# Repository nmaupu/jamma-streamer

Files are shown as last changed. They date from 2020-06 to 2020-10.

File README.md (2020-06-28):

# jamma-streamer

Jamma PCB video recorder and more (hardware)

# Eagle library and parts used

* `nma-eagle` library: https://github.com/nmaupu/electronics/blob/master/eagle-libs/nma-eagle.lbr
* SparkFun libraries (https://github.com/sparkfun/SparkFun-Eagle-Libraries):
  - SparkFun-Connectors
  - SparkFun-IC-Comms
  - SparkFun-PowerSymbols
  - SparkFun-Retired
* Default eagle libraries:
  - linear
  - pinhead
  - jumper

# BOM (Bill Of Materials) generation

To generate the BOM, use process described in [electronics](https://github.com/nmaupu/electronics) repository !

# RTC

## Interrupts for milliseconds counting

* We will be using the chip `DS3231`. Pin `INT/SWQ` is the one.
* Datasheet https://datasheets.maximintegrated.com/en/ds/DS3231.pdf page 13 indicates how to configure the register to enable a 1KHz signal on this pin.
* The configuration of the register should be: `0b10001000`.
* Configuration is done using I2C protocol.
* `PC3` for `pin change interrupt` on the ATmega side.

Example on how to use `PCINT` is available here: https://gist.github.com/Wollw/2598827

Example on how to configure chip registers via I2C: https://github.com/FabioCuomo/FabioCuomo-DS3231/blob/master/RTClibExtended.cpp

# Buttons detection

Buttons detection are done using shift registers (8 bits parallel in / serial out such as the 75HC165).
The code used is strongly inspired from the following tutorial:
https://playground.arduino.cc/Code/ShiftRegSN74HC165N

# uSDCARD writing

Source:
https://learn.adafruit.com/adafruit-micro-sd-breakout-board-card-tutorial?view=all

Beware: Arduino pins number and macros you can use in your code are sometimes not equivalent to what you expect when using third party libraries like the one used for SD card... One example is the pin `PB2` (Arduino's pin number 10) used for `CS`. If you use the library's macro `PB2`, it sets the pin to number `2` instead of `10`... This leads to long painful debugging session...

Here is an image with all pin numbers as a reference:
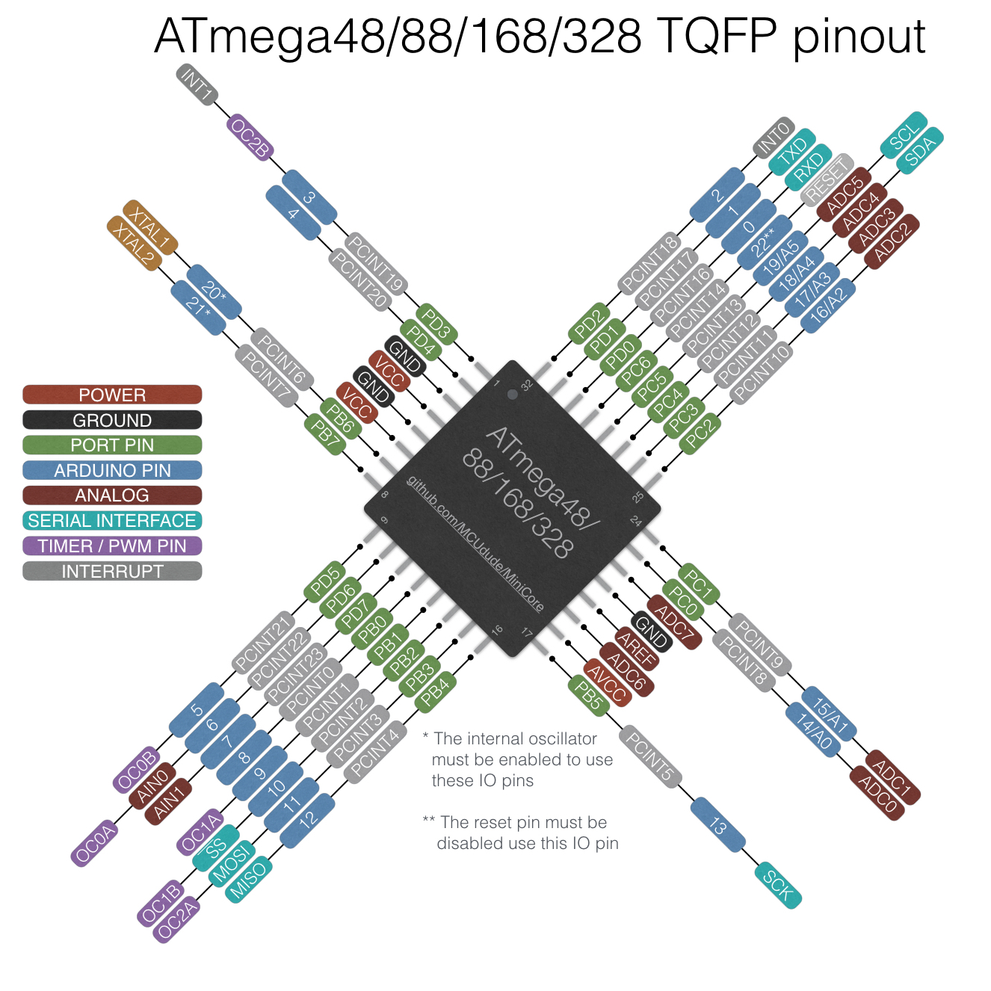
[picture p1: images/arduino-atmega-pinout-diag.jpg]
Arduino ATmega pinout diagram


# How to program the ATMEGA328PB

## Fuses

Fuses can be calculated using: https://www.engbedded.com/fusecalc/

More info here: http://www.martyncurrey.com/arduino-atmega-328p-fuse-settings/

## Using arduino bootloader (for debugging and fast upload via IDE)

We are going to use [Minicore](https://github.com/MCUdude/MiniCore) as it supports ATmega328PB used on this project.

---

Use the following procedure:

- First install minicore boards following the [procedure](https://github.com/MCUdude/MiniCore#boards-manager-installation).

Use *arduino as ISP* method to upload the bootloader:
  - configure your IDE to use the source Arduino which will act as a programmer (ISP programmer)
  - upload Arduino ISP sketch to the arduino board to make it act as an *ISP programmer* (available as example sketch from the Arduino IDE)
  - plug all *Jamma Streamer's ICSP* to *Arduino ICSP* except *RST* both sides
  - *RST Jamma Streamer* (from ICSP) to *pin 10* of the Arduino (this will act as the reset pin)
  - plug a 10uF capacitor between Arduino RESET (capacitor +) and GND (capacitor -)

Now configure the board as per the following:
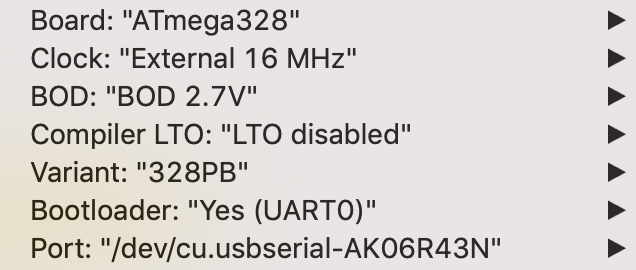
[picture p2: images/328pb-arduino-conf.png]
Arduino configuration for Minicore / ATmega328PB


Your arduino is ready for ISP. Now you can configure to burn the bootloader:
  - `Tools > Port`: select the arduino device
  - `Tools > Burn Bootloader`

This should work as expected. From now on, you will be able to upload sketches via *NMA Jamma Streamer* USB port directly!

Fuses consideration:
  - *Minicore* is forked from *Optiboot* (official Arduino UNO bootloader) and is `512 bytes` long.
  - We are using an external crystal oscillator (and not the internal one).
  - `EEPROM` save is enabled (this avoid erasing it at each upload reducing its lifetime).
  - `BOOTSZ1` and `BOOTSZ2` are both disabled because 512 bytes can fit into the minimal 256 words (1 word = 2 bytes).
  - `BOOTRST` is set to indicate we are using a bootloader.
  - `BODLEVEL1` (2.7V) is enabled because why not.

This give the following fuses:
  - low fuse: `0xff`
  - high fuse: `0xd6`
  - extended fuse: `0xf5` (Normally, it would be `0xfd` but after burning, there is a warning so `f5` is a good value)

## Without using arduino bootloader for runtime

We are using Jamma Streamer board ICSP header for this.
No need for a Arduino bootloader, we will be uploading sketch directly via ICSP header !

As I am using Atmega328PB (instead of P), Arduino IDE is not recognizing at first, we need to install this first to have the board available in Arduino’s IDE later on:
https://github.com/nmaupu/ATmega328PB-Testing

---

Plug cables as follow (using Arduino Duemilanove or Mega):

- All ICSP to Arduino ICSP except RST both sides
- RST Jamma Streamer (from icsp) to pin 10 of the arduino
- Plug Arduino via USB to computer and upload ArduinoISP sketch onto it.
- plug a 10uF capacitor between Arduino RESET (capacitor +) and GND (capacitor -)
- select tools > boards > atmega328PB Crystal Clock
- `sketch > Upload using programmer`

This will program the NMA Jamma Streamer ATmega328PB !

## Burn / read fuses (use the crystal oscillator instead of internal one)

Use an external Arduino board to act as an ISP programmer like before:

- All ICSP to Arduino ICSP except RST both sides
- RST Jamma Streamer (from icsp) to pin 10 of the arduino
- Plug Arduino via USB to computer and upload ArduinoISP sketch onto it.
- plug a 10uF capacitor between Arduino RESET (capacitor +) and GND (capacitor -)

To read the fuses, simply execute:
```
avrdude -C /Users/nicolas_maupu/Library/Arduino15/packages/MiniCore/hardware/avr/2.0.5/avrdude.conf \
  -p atmega328pb -c stk500v1 -P /dev/cu.usbmodem141101 -b19200 \
  -U hfuse:r:-:h -U efuse:r:-:h -U lfuse:r:-:h
```

To burn fuses:
```
avrdude -C /Users/nicolas_maupu/Library/Arduino15/packages/MiniCore/hardware/avr/2.0.5/avrdude.conf \
  -v -p atmega328pb -c stk500v1 -P /dev/cu.usbmodem141101 -b19200 \
  -e -Ulock:w:0x3f:m -Uefuse:w:0xF5:m -Uhfuse:w:0xd6:m -Ulfuse:w:0xff:m 
```

To burn the Minicore bootloader:
```
avrdude -C /Users/nicolas_maupu/Library/Arduino15/packages/MiniCore/hardware/avr/2.0.5/avrdude.conf \
  -v -p atmega328pb -c stk500v1 -P /dev/cu.usbmodem141101 -b19200 \
  -Uflash:w:$HOME/Library/Arduino15/packages/MiniCore/hardware/avr/2.0.5/bootloaders/optiboot_flash/bootloaders/atmega328pb/16000000L/optiboot_flash_atmega328pb_UART0_115200_16000000L_B5.hex:i \
  -Ulock:w:0x0f:m 
```

# Thanks

- https://github.com/Shinichi-Ohki/JAMMA_connector_for_eagle
- https://github.com/watterott/wattuino

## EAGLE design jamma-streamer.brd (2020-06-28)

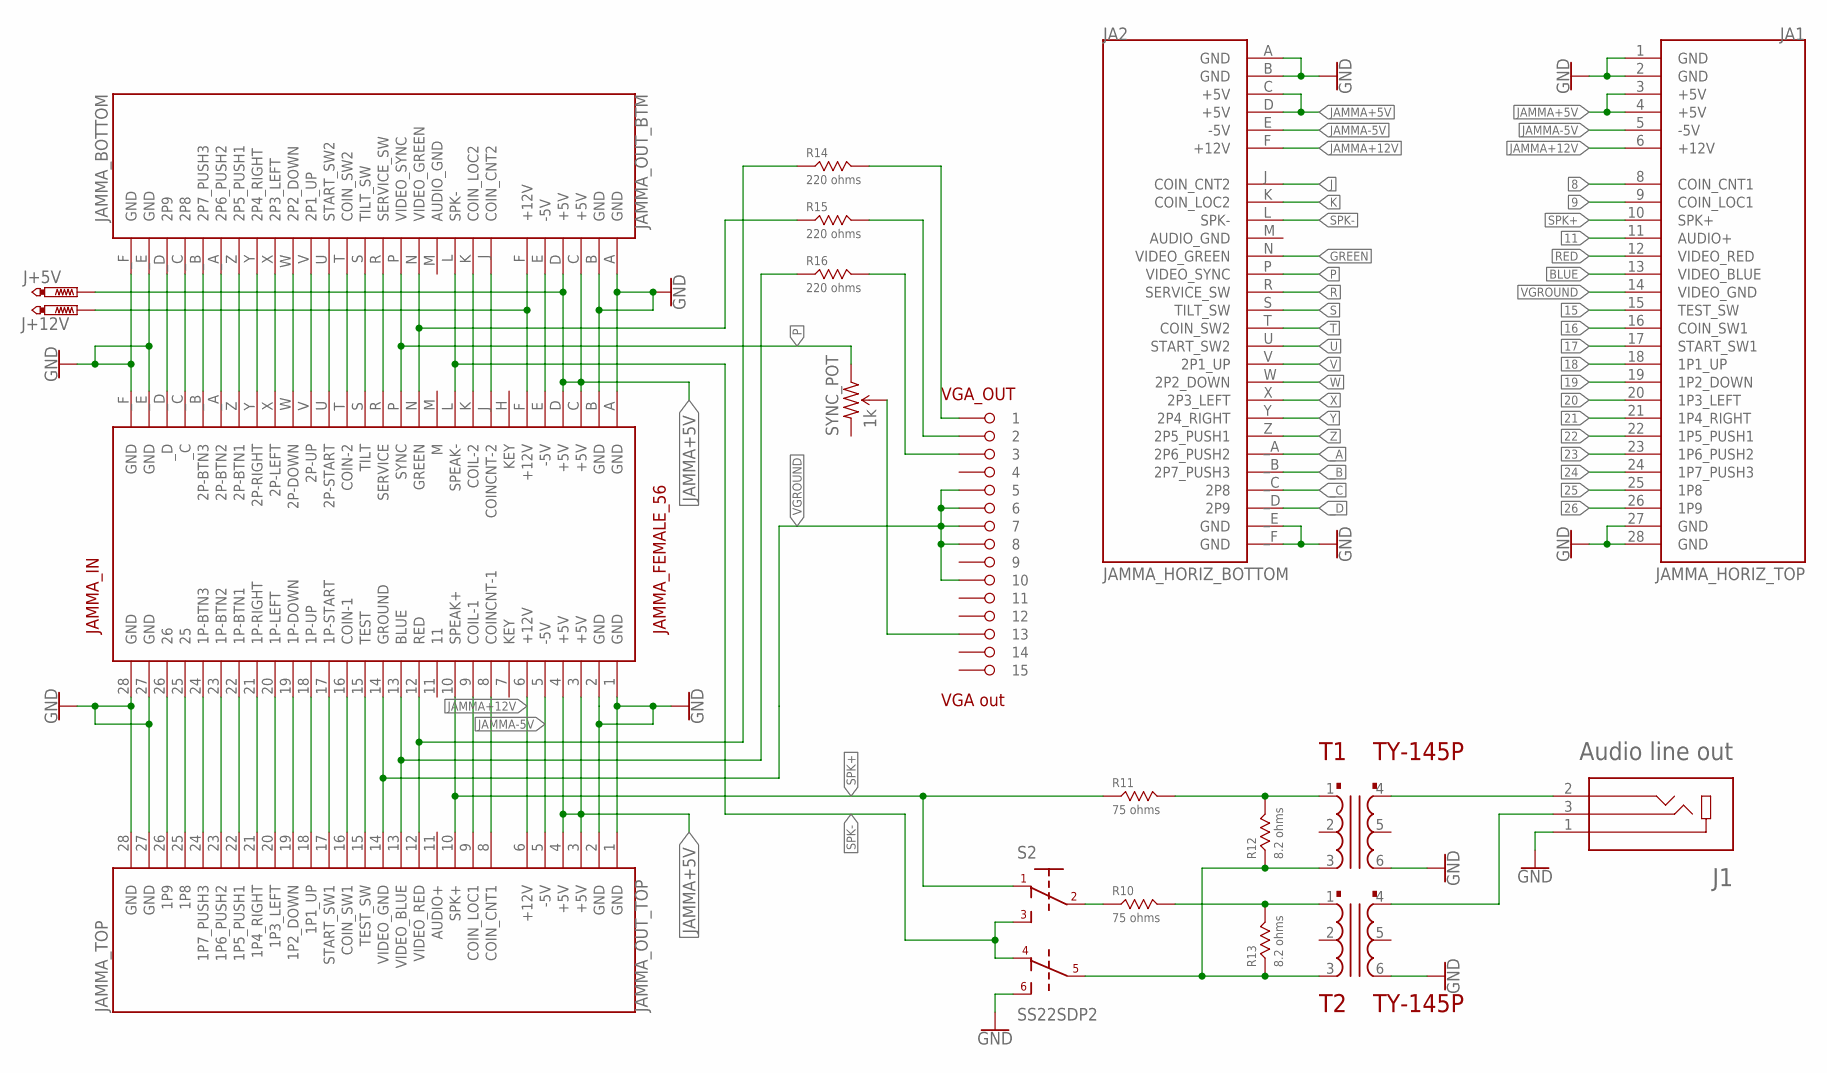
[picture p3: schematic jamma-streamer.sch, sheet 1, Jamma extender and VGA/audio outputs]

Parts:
J1: Audio line out; CUI_SJ1-3523N
J+5V, J+12V: PTR1TP15SQ; TP15SQ
JA1: JAMMA_HORIZ_TOP
JA2: JAMMA_HORIZ_BOTTOM
JAMMA_IN: JAMMA_FEMALE_56
JAMMA_OUT_BTM: JAMMA_BOTTOM
JAMMA_OUT_TOP: JAMMA_TOP
R10, R11: 75 ohms; TE_3550_SERIES; MOUSER_REF 279-355075RFT
R12, R13: 8.2 ohms; TE_3550_SERIES; MOUSER_REF 279-35508R2JT
R14, R15, R16: 220 ohms; RESC3225X70N
S2: SS22SDP2; SS22SDP2(DPDT)
SYNC_POT: 1k; TRIM_POT_PTH
T1, T2: TY-145P; TRIAD-TY-145P
VGA_OUT: VGA out; HARTING-DSUB-15-FEMALE

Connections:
8: JA1.8 (COIN_CNT1), JAMMA_IN.8 (COINCNT-1), JAMMA_OUT_TOP.8 (COIN_CNT1)
9: JA1.9 (COIN_LOC1), JAMMA_IN.9 (COIL-1), JAMMA_OUT_TOP.9 (COIN_LOC1)
11: JA1.11 (AUDIO+)
15: JA1.15 (TEST_SW), JAMMA_IN.15 (TEST), JAMMA_OUT_TOP.15 (TEST_SW); also elsewhere on the board
16: JA1.16 (COIN_SW1), JAMMA_IN.16 (COIN-1), JAMMA_OUT_TOP.16 (COIN_SW1); also elsewhere on the board
17: JA1.17 (START_SW1), JAMMA_IN.17 (1P-START), JAMMA_OUT_TOP.17 (START_SW1); also elsewhere on the board
18: JA1.18 (1P1_UP), JAMMA_IN.18 (1P-UP), JAMMA_OUT_TOP.18 (1P1_UP); also elsewhere on the board
19: JA1.19 (1P2_DOWN), JAMMA_IN.19 (1P-DOWN), JAMMA_OUT_TOP.19 (1P2_DOWN); also elsewhere on the board
20: JA1.20 (1P3_LEFT), JAMMA_IN.20 (1P-LEFT), JAMMA_OUT_TOP.20 (1P3_LEFT); also elsewhere on the board
21: JA1.21 (1P4_RIGHT), JAMMA_IN.21 (1P-RIGHT), JAMMA_OUT_TOP.21 (1P4_RIGHT); also elsewhere on the board
22: JA1.22 (1P5_PUSH1), JAMMA_IN.22 (1P-BTN1), JAMMA_OUT_TOP.22 (1P5_PUSH1); also elsewhere on the board
23: JA1.23 (1P6_PUSH2), JAMMA_IN.23 (1P-BTN2), JAMMA_OUT_TOP.23 (1P6_PUSH2); also elsewhere on the board
24: JA1.24 (1P7_PUSH3), JAMMA_IN.24 (1P-BTN3), JAMMA_OUT_TOP.24 (1P7_PUSH3); also elsewhere on the board
25: JA1.25 (1P8), JAMMA_IN.25, JAMMA_OUT_TOP.25 (1P8); also elsewhere on the board
26: JA1.26 (1P9), JAMMA_IN.26, JAMMA_OUT_TOP.26 (1P9); also elsewhere on the board
BLUE: JA1.13 (VIDEO_BLUE), JAMMA_IN.13 (BLUE), JAMMA_OUT_TOP.13 (VIDEO_BLUE), R16.1
GND: J1.1, JA1.1 (GND), JA1.2 (GND), JA1.27 (GND), JA1.28 (GND), JA2.A (GND), JA2.B (GND), JA2._E (GND), JA2._F (GND), JAMMA_IN.1 (GND), JAMMA_IN.2 (GND), JAMMA_IN.27 (GND), JAMMA_IN.28 (GND), JAMMA_IN.A (GND), JAMMA_IN.B (GND), JAMMA_IN._E (GND), JAMMA_IN._F (GND), JAMMA_OUT_BTM.A (GND), JAMMA_OUT_BTM.B (GND), JAMMA_OUT_BTM._E (GND), JAMMA_OUT_BTM._F (GND), JAMMA_OUT_TOP.1 (GND), JAMMA_OUT_TOP.2 (GND), JAMMA_OUT_TOP.27 (GND), JAMMA_OUT_TOP.28 (GND), S2.6, T1.6, T2.6; also elsewhere on the board
GREEN: JA2.N (VIDEO_GREEN), JAMMA_IN.N (GREEN), JAMMA_OUT_BTM.N (VIDEO_GREEN), R15.1
J: JA2.J (COIN_CNT2), JAMMA_IN.J (COINCNT-2), JAMMA_OUT_BTM.J (COIN_CNT2)
JAMMA+5V: J+5V.TP, JA1.3 (+5V), JA1.4 (+5V), JA2.C (+5V), JA2.D (+5V), JAMMA_IN.3 (+5V), JAMMA_IN.4 (+5V), JAMMA_IN.C (+5V), JAMMA_IN.D (+5V), JAMMA_OUT_BTM.C (+5V), JAMMA_OUT_BTM.D (+5V), JAMMA_OUT_TOP.3 (+5V), JAMMA_OUT_TOP.4 (+5V)
JAMMA+12V: J+12V.TP, JA1.6 (+12V), JA2.F (+12V), JAMMA_IN.6 (+12V), JAMMA_IN.F (+12V), JAMMA_OUT_BTM.F (+12V), JAMMA_OUT_TOP.6 (+12V); also elsewhere on the board
JAMMA-5V: JA1.5 (-5V), JA2.E (-5V), JAMMA_IN.5 (-5V), JAMMA_IN.E (-5V), JAMMA_OUT_BTM.E (-5V), JAMMA_OUT_TOP.5 (-5V)
K: JA2.K (COIN_LOC2), JAMMA_IN.K (COIL-2), JAMMA_OUT_BTM.K (COIN_LOC2)
unnamed: R14.2, VGA_OUT.1
unnamed: R15.2, VGA_OUT.2
unnamed: SYNC_POT.2 (WIPER), VGA_OUT.13
unnamed: R10.1, S2.2
unnamed: R11.2, R12.2, T1.1
unnamed: R10.2, R13.2, T2.1
unnamed: R16.2, VGA_OUT.3
unnamed: R12.1, R13.1, S2.5, T1.3, T2.3
unnamed: J1.2, T1.4
unnamed: J1.3, T2.4
P: JA2.P (VIDEO_SYNC), JAMMA_IN.P (SYNC), JAMMA_OUT_BTM.P (VIDEO_SYNC), SYNC_POT.1 (CCW)
R: JA2.R (SERVICE_SW), JAMMA_IN.R (SERVICE), JAMMA_OUT_BTM.R (SERVICE_SW); also elsewhere on the board
RED: JA1.12 (VIDEO_RED), JAMMA_IN.12 (RED), JAMMA_OUT_TOP.12 (VIDEO_RED), R14.1
S: JA2.S (TILT_SW), JAMMA_IN.S (TILT), JAMMA_OUT_BTM.S (TILT_SW)
SPK+: JA1.10 (SPK+), JAMMA_IN.10 (SPEAK+), JAMMA_OUT_TOP.10 (SPK+), R11.1, S2.1
SPK-: JA2.L (SPK-), JAMMA_IN.L (SPEAK-), JAMMA_OUT_BTM.L (SPK-), S2.3, S2.4
T: JA2.T (COIN_SW2), JAMMA_IN.T (COIN-2), JAMMA_OUT_BTM.T (COIN_SW2); also elsewhere on the board
U: JA2.U (START_SW2), JAMMA_IN.U (2P-START), JAMMA_OUT_BTM.U (START_SW2); also elsewhere on the board
V: JA2.V (2P1_UP), JAMMA_IN.V (2P-UP), JAMMA_OUT_BTM.V (2P1_UP); also elsewhere on the board
VGROUND: JA1.14 (VIDEO_GND), JAMMA_IN.14 (GROUND), JAMMA_OUT_TOP.14 (VIDEO_GND), VGA_OUT.5, VGA_OUT.6, VGA_OUT.7, VGA_OUT.8, VGA_OUT.10
W: JA2.W (2P2_DOWN), JAMMA_IN.W (2P-DOWN), JAMMA_OUT_BTM.W (2P2_DOWN); also elsewhere on the board
X: JA2.X (2P3_LEFT), JAMMA_IN.X (2P-LEFT), JAMMA_OUT_BTM.X (2P3_LEFT); also elsewhere on the board
Y: JA2.Y (2P4_RIGHT), JAMMA_IN.Y (2P-RIGHT), JAMMA_OUT_BTM.Y (2P4_RIGHT); also elsewhere on the board
Z: JA2.Z (2P5_PUSH1), JAMMA_IN.Z (2P-BTN1), JAMMA_OUT_BTM.Z (2P5_PUSH1); also elsewhere on the board
_A: JA2._A (2P6_PUSH2), JAMMA_IN._A (2P-BTN2), JAMMA_OUT_BTM._A (2P6_PUSH2); also elsewhere on the board
_B: JA2._B (2P7_PUSH3), JAMMA_IN._B (2P-BTN3), JAMMA_OUT_BTM._B (2P7_PUSH3); also elsewhere on the board
_C: JA2._C (2P8), JAMMA_IN._C, JAMMA_OUT_BTM._C (2P8); also elsewhere on the board
_D: JA2._D (2P9), JAMMA_IN._D, JAMMA_OUT_BTM._D (2P9); also elsewhere on the board

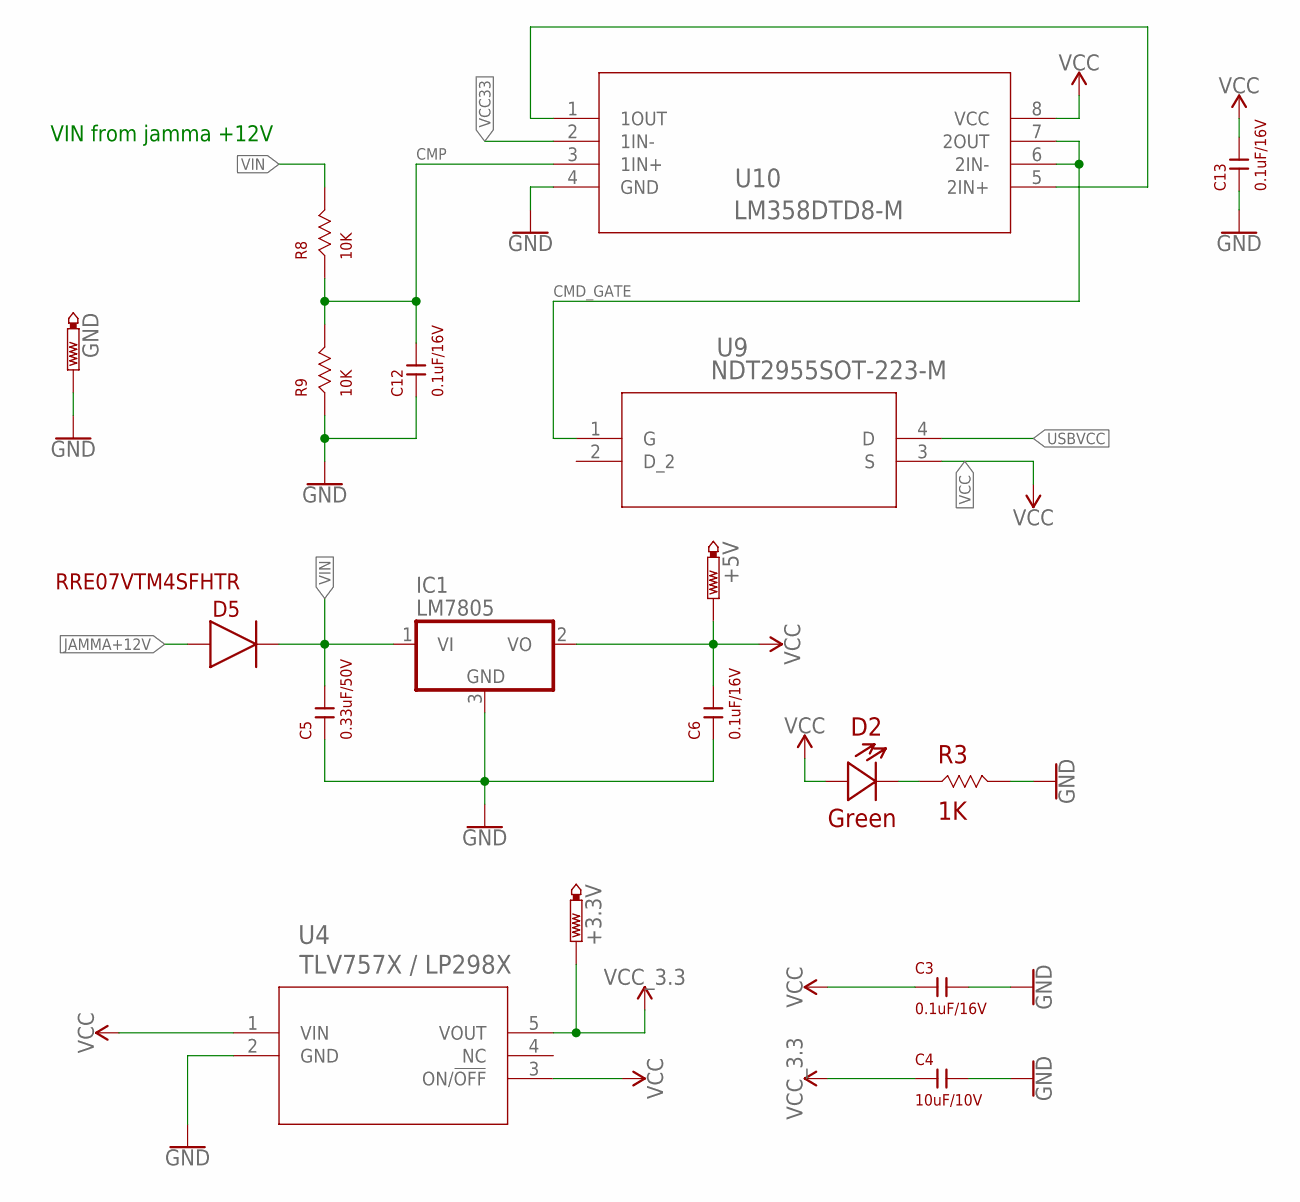
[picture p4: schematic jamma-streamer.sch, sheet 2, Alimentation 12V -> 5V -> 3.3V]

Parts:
+3.3V, +5V: PTR1TP15SQ; TP15SQ
C3, C6, C12, C13: 0.1uF/16V; KEMET-C1210C104K4J
C4: 10uF/10V; KEMET-C1210C106K8N
C5: 0.33uF/50V; KEMET-C1206X334K5R
D2: Green; 604-APTD1608LCGCK
D5: RRE07VTM4SFHTR; DIODE-RRE07VTM4SFHTR
GND: PTR1TP15SQ; TP15SQ
IC1: LM7805; TO252; MOUSER_REF 621-AS7805ADTR-G1
R3: 1K; 652-CHP0603FX1001ELF
R8, R9: 10K; BOURNS-CRM2512AJW-103ELF
U4: TLV757X / LP298X; DBV5-M
U9: NDT2955SOT-223-M; SOT-223-M
U10: LM358DTD8-M; D8-M

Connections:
CMD_GATE: U9.1 (G), U10.6 (2IN-), U10.7 (2OUT)
CMP: C12.1, R8.1, R9.2, U10.3 (1IN+)
GND: C3.1, C4.1, C5.2, C6.2, C12.2, C13.2, GND.TP, IC1.3 (GND), R3.2, R9.1, U4.2 (GND), U10.4 (GND); also elsewhere on the board
JAMMA+12V: D5.2; also elsewhere on the board
unnamed: D2.-, R3.1
unnamed: U10.1 (1OUT), U10.5 (2IN+)
USBVCC: U9.4 (D); also elsewhere on the board
VCC: +5V.TP, C3.2, C6.1, C13.1, D2.+, IC1.2 (VO), U4.1 (VIN), U4.3 (ON/!OFF), U9.3 (S), U10.8 (VCC); also elsewhere on the board
VCC33: U10.2 (1IN-); also elsewhere on the board
VCC_2: +3.3V.TP, C4.2, U4.5 (VOUT); also elsewhere on the board
VIN: C5.1, D5.1, IC1.1 (VI), R8.2

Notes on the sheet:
VIN from jamma +12V

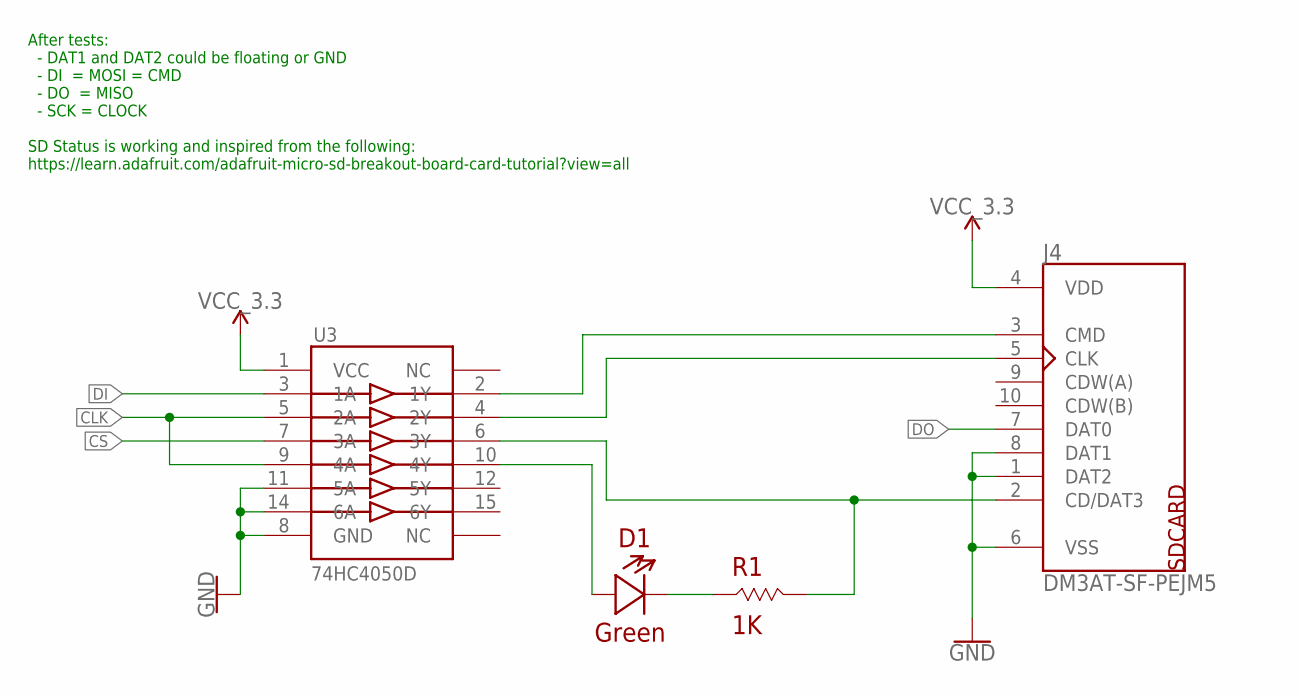
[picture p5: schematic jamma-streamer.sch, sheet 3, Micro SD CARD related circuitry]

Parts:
D1: Green; 604-APTD1608LCGCK
J4: DM3AT-SF-PEJM5; DM3AT-SF-PEJM5_1
R1: 1K; 652-CHP0603FX1001ELF
U3: 74HC4050D; SO16

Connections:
CLK: U3.5 (2A), U3.9 (4A); also elsewhere on the board
CS: U3.7 (3A); also elsewhere on the board
DI: U3.3 (1A); also elsewhere on the board
DO: J4.7 (DAT0); also elsewhere on the board
GND: J4.1 (DAT2), J4.6 (VSS), J4.8 (DAT1), U3.8 (GND), U3.11 (5A), U3.14 (6A); also elsewhere on the board
unnamed: D1.+, U3.10 (4Y)
unnamed: D1.-, R1.1
SD_CLK: J4.5 (CLK), U3.4 (2Y)
SD_CMD: J4.3 (CMD), U3.2 (1Y)
SD_CS: J4.2 (CD/DAT3), R1.2, U3.6 (3Y)
VCC_2: J4.4 (VDD), U3.1 (VCC); also elsewhere on the board

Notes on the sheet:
After tests: - DAT1 and DAT2 could be floating or GND - DI = MOSI = CMD - DO = MISO - SCK = CLOCK SD Status is working and inspired from the following: https://learn.adafruit.com/adafruit-micro-sd-breakout-board-card-tutorial?view=all

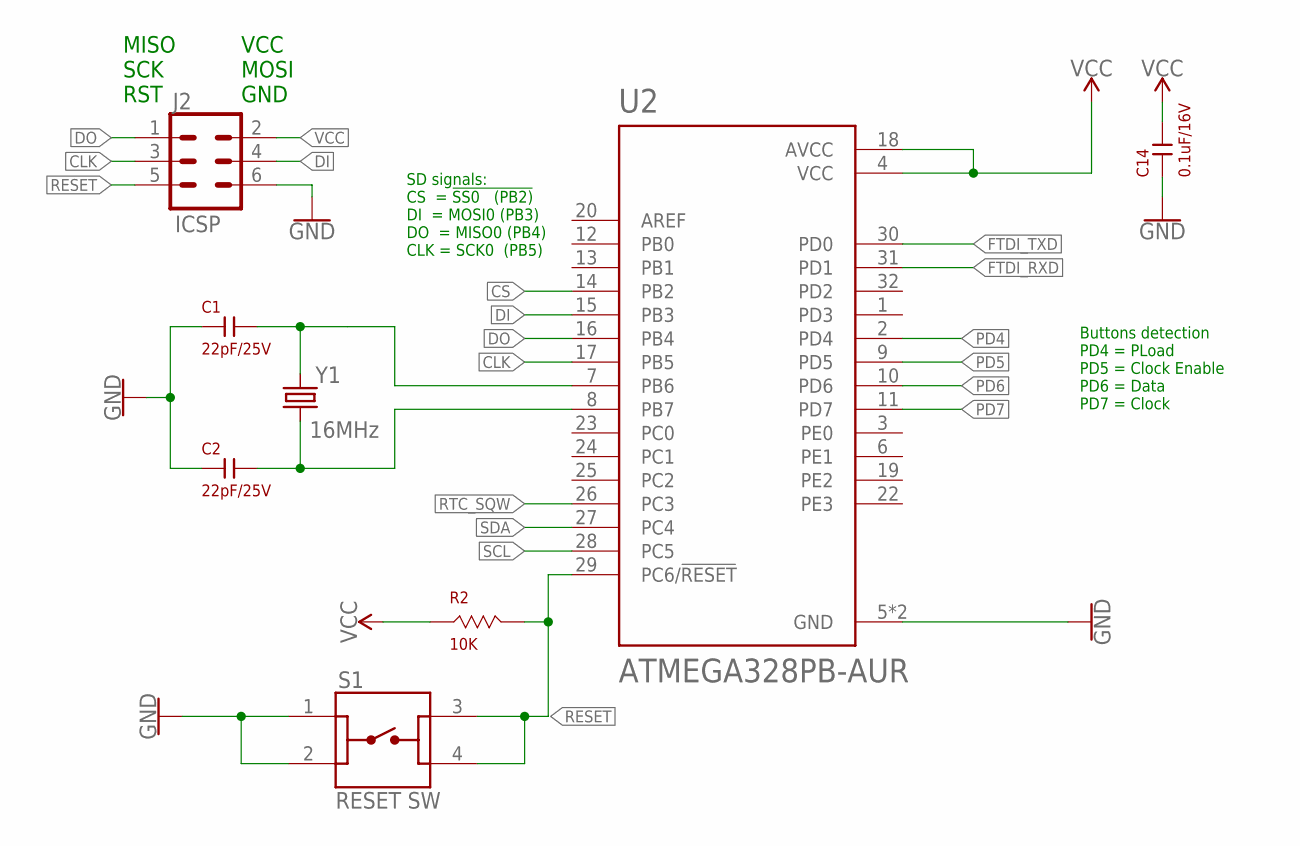
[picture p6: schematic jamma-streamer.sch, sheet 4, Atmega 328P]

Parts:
C1, C2: 22pF/25V; KEMET-C1206C220K3HACTU
C14: 0.1uF/16V; KEMET-C1210C104K4J
J2: ICSP; 2X3; MOUSER_REF 649-773134AE26LF
R2: 10K; BOURNS-CRM2512AJW-103ELF
S1: RESET SW; SW_1825910-7
U2: ATMEGA328PB-AUR; QFP80P900X900X120-32N
Y1: 16MHz; HC49US

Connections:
CLK: J2.3, U2.17 (PB5); also elsewhere on the board
CS: U2.14 (PB2); also elsewhere on the board
DI: J2.4, U2.15 (PB3); also elsewhere on the board
DO: J2.1, U2.16 (PB4); also elsewhere on the board
FTDI_RXD: U2.31 (PD1); also elsewhere on the board
FTDI_TXD: U2.30 (PD0); also elsewhere on the board
GND: C1.2, C2.2, C14.2, J2.6, S1.1, S1.2, U2.5 (GND), U2.21 (GND); also elsewhere on the board
PB6: C1.1, U2.7 (PB6), Y1.2
PB7: C2.1, U2.8 (PB7), Y1.1
PD4: U2.2 (PD4); also elsewhere on the board
PD5: U2.9 (PD5); also elsewhere on the board
PD6: U2.10 (PD6); also elsewhere on the board
PD7: U2.11 (PD7); also elsewhere on the board
RESET: J2.5, R2.2, S1.3, S1.4, U2.29 (PC6/!RESET); also elsewhere on the board
RTC_SQW: U2.26 (PC3); also elsewhere on the board
SCL: U2.28 (PC5); also elsewhere on the board
SDA: U2.27 (PC4); also elsewhere on the board
VCC: C14.1, J2.2, R2.1, U2.4 (VCC), U2.18 (AVCC); also elsewhere on the board

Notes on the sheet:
SD signals: CS = !SS0 (PB2) DI = MOSI0 (PB3) DO = MISO0 (PB4) CLK = SCK0 (PB5)
Buttons detection PD4 = PLoad PD5 = Clock Enable PD6 = Data PD7 = Clock
MISO SCK RST
VCC MOSI GND

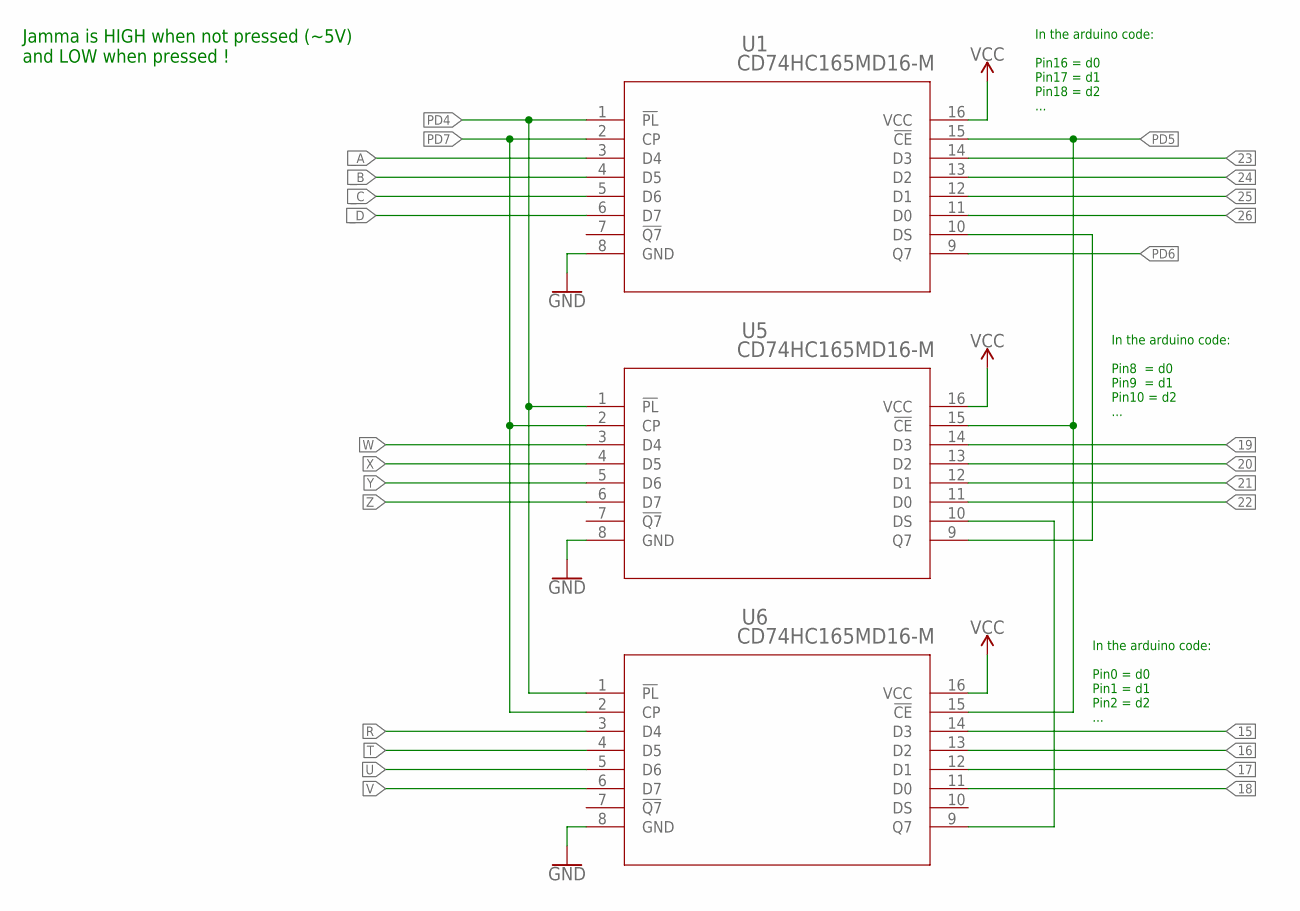
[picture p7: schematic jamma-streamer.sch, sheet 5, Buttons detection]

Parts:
U1, U5, U6: CD74HC165MD16-M; D16-M

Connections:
15: U6.14 (D3); also elsewhere on the board
16: U6.13 (D2); also elsewhere on the board
17: U6.12 (D1); also elsewhere on the board
18: U6.11 (D0); also elsewhere on the board
19: U5.14 (D3); also elsewhere on the board
20: U5.13 (D2); also elsewhere on the board
21: U5.12 (D1); also elsewhere on the board
22: U5.11 (D0); also elsewhere on the board
23: U1.14 (D3); also elsewhere on the board
24: U1.13 (D2); also elsewhere on the board
25: U1.12 (D1); also elsewhere on the board
26: U1.11 (D0); also elsewhere on the board
GND: U1.8 (GND), U5.8 (GND), U6.8 (GND); also elsewhere on the board
unnamed: U5.10 (DS), U6.9 (Q7)
unnamed: U1.10 (DS), U5.9 (Q7)
PD4: U1.1 (!PL), U5.1 (!PL), U6.1 (!PL); also elsewhere on the board
PD5: U1.15 (!CE), U5.15 (!CE), U6.15 (!CE); also elsewhere on the board
PD6: U1.9 (Q7); also elsewhere on the board
PD7: U1.2 (CP), U5.2 (CP), U6.2 (CP); also elsewhere on the board
R: U6.3 (D4); also elsewhere on the board
T: U6.4 (D5); also elsewhere on the board
U: U6.5 (D6); also elsewhere on the board
V: U6.6 (D7); also elsewhere on the board
VCC: U1.16 (VCC), U5.16 (VCC), U6.16 (VCC); also elsewhere on the board
W: U5.3 (D4); also elsewhere on the board
X: U5.4 (D5); also elsewhere on the board
Y: U5.5 (D6); also elsewhere on the board
Z: U5.6 (D7); also elsewhere on the board
_A: U1.3 (D4); also elsewhere on the board
_B: U1.4 (D5); also elsewhere on the board
_C: U1.5 (D6); also elsewhere on the board
_D: U1.6 (D7); also elsewhere on the board

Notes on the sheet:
Jamma is HIGH when not pressed (~5V) and LOW when pressed !
In the arduino code: Pin0 = d0 Pin1 = d1 Pin2 = d2 ...
In the arduino code: Pin8 = d0 Pin9 = d1 Pin10 = d2 ...
In the arduino code: Pin16 = d0 Pin17 = d1 Pin18 = d2 ...

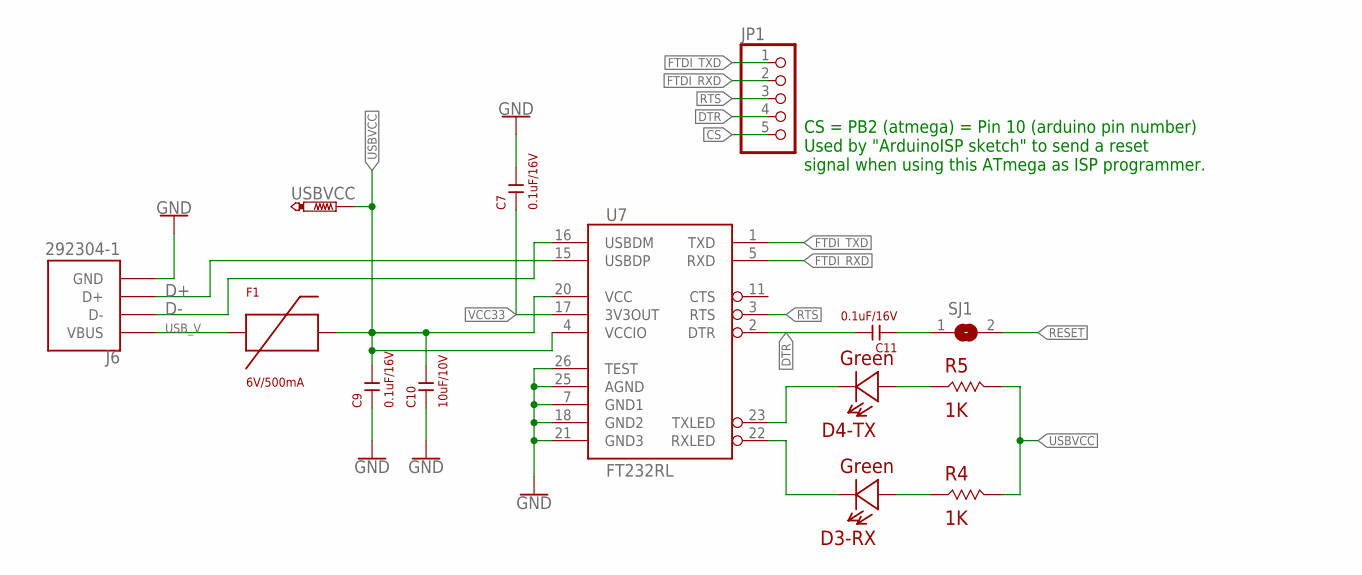
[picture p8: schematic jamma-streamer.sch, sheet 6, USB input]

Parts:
C7, C9, C11: 0.1uF/16V; KEMET-C1210C104K4J
C10: 10uF/10V; KEMET-C1210C106K8N
D3-RX, D4-TX: Green; 604-APTD1608LCGCK
F1: 6V/500mA; FUSE-1206L050YR
J6: 292304-1; TE_292304-1
JP1: PINHD-1X5; 1X05; MOUSER_REF 798-A23PA254DSA71
R4, R5: 1K; 652-CHP0603FX1001ELF
SJ1: SJ
U7: FT232RL; SSOP28DB
USBVCC: PTR1TP15SQ; TP15SQ

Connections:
CS: JP1.5; also elsewhere on the board
D+: J6.3 (D+), U7.15 (USBDP)
D-: J6.2 (D-), U7.16 (USBDM)
DTR: C11.1, JP1.4, U7.2 (DTR)
FTDI_RXD: JP1.2, U7.5 (RXD); also elsewhere on the board
FTDI_TXD: JP1.1, U7.1 (TXD); also elsewhere on the board
GND: C7.1, C9.2, C10.2, J6.4 (GND), U7.7 (GND1), U7.18 (GND2), U7.21 (GND3), U7.25 (AGND), U7.26 (TEST); also elsewhere on the board
unnamed: D3-RX.-, U7.22 (RXLED)
unnamed: C11.2, SJ1.1
unnamed: D4-TX.-, U7.23 (TXLED)
unnamed: D4-TX.+, R5.1
unnamed: D3-RX.+, R4.1
RESET: SJ1.2; also elsewhere on the board
RTS: JP1.3, U7.3 (RTS)
USBVCC: C9.1, C10.1, F1.2, R4.2, R5.2, U7.4 (VCCIO), U7.20 (VCC), USBVCC.TP; also elsewhere on the board
USB_V: F1.1, J6.1 (VBUS)
VCC33: C7.2, U7.17 (3V3OUT); also elsewhere on the board

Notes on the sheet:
CS = PB2 (atmega) = Pin 10 (arduino pin number) Used by "ArduinoISP sketch" to send a reset signal when using this ATmega as ISP programmer.

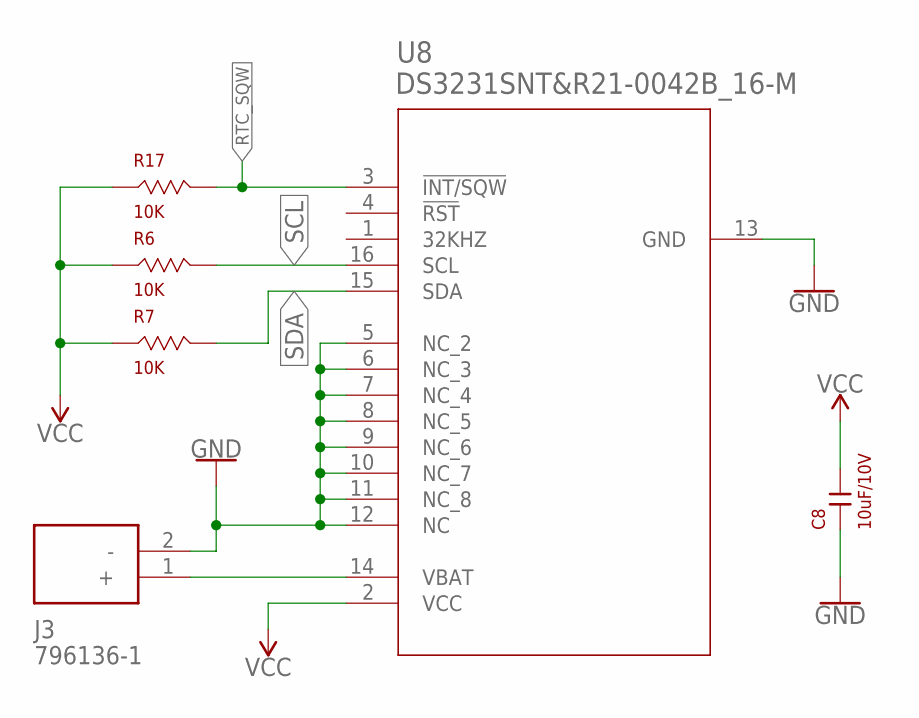
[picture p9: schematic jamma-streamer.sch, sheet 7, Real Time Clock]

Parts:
C8: 10uF/10V; KEMET-C1210C106K8N
J3: 796136-1
R6, R7, R17: 10K; BOURNS-CRM2512AJW-103ELF
U8: DS3231SNT&R21-0042B_16-M; 21-0042B_16-M

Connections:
GND: C8.2, J3.2 (-), U8.5 (NC_2), U8.6 (NC_3), U8.7 (NC_4), U8.8 (NC_5), U8.9 (NC_6), U8.10 (NC_7), U8.11 (NC_8), U8.12 (NC), U8.13 (GND); also elsewhere on the board
unnamed: J3.1 (+), U8.14 (VBAT)
RTC_SQW: R17.2, U8.3 (!INT/SQW); also elsewhere on the board
SCL: R6.2, U8.16 (SCL); also elsewhere on the board
SDA: R7.2, U8.15 (SDA); also elsewhere on the board
VCC: C8.1, R6.1, R7.1, R17.1, U8.2 (VCC); also elsewhere on the board

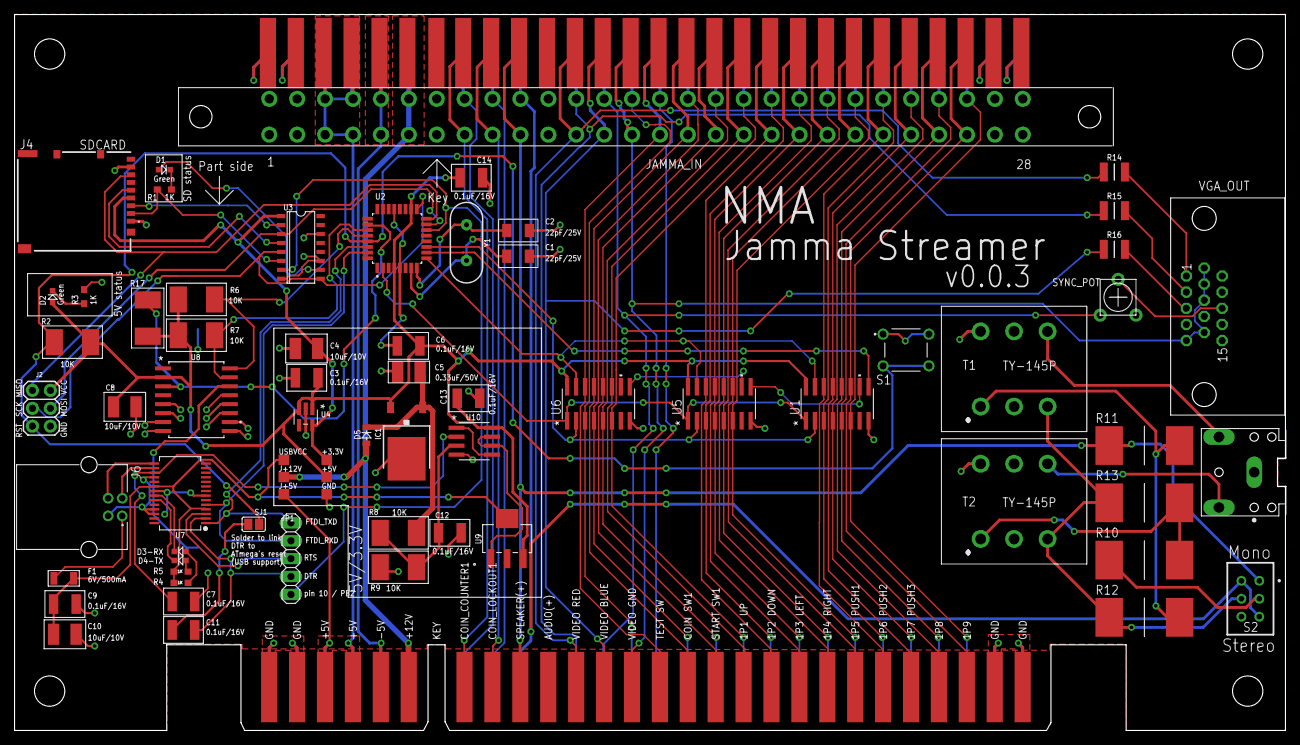
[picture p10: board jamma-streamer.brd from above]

Board: 2 copper layers, 180.3 x 101.6 mm, 73 parts (1 on the bottom side), 93 nets.

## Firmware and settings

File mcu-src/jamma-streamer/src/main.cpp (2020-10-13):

#include "globals.h"
#include "btns/buttonDetector.h"
#include "rtc/jammaTime.h"
#include "storage/sdstorage.h"
#include "storage/eventWriter.h"

void serialLoggerButtonCallback(ButtonEvent* e);
void sdcardLoggerButtonCallback(ButtonEvent* e);

// Singleton objects
ButtonDetector* detector;
const ButtonsState* st;
const ButtonsState* prev_st;

char logFilename[32];
SDStorage* sto;

JammaTime* time;

EventWriter* writer;

//
void setup() {
    Serial.begin(SERIAL_SPEED);
    while (!Serial) {
        ;  // wait for serial port to connect. Needed for native USB port only
    }

    Serial.println(APP_NAME);
    Serial.print("version: ");
    Serial.println(APP_VERSION);
    Serial.println();

    // Buttons detection
    Serial.print("Configuring buttons detection...");
    detector = new ButtonDetector(PLOAD, ENABLE, DATA, CLOCK);
    detector->addButtonEventListener(serialLoggerButtonCallback);
    detector->addButtonEventListener(sdcardLoggerButtonCallback);
    Serial.println("OK");

    // RTC - Real Time Clock
    Serial.print("Initializing RTC...");
    time = new JammaTime();
    Serial.println("OK");

    Serial.print("Initializing SD card...");
    //sprintf(logFilename, "jamma_%s.txt", time->getJammaTime());
    sprintf(logFilename, "/001.log");
    sto = new SDStorage(SD_CS, SD_MOSI,SD_MISO, SD_CLK, logFilename);
    if(!sto->initSDCard()) {
        Serial.println("Failed. Card present ? Formatted as FAT16/32 ?");
    } else {
        Serial.printf("OK - log file name is %s\n", logFilename);
    }

    // Creating writer object
    writer = new EventWriter(sto, time);

    Serial.println("Listening for inputs.");
    Serial.flush();
}

void loop() {
#ifdef DEBUG_RTC
    Serial.print(", time=");
    Serial.println(time->getJammaTime());
#endif

    detector->loadRegisters();
    detector->readRegisters();

#ifdef DEBUG_BUTTONS
    detector->printSerial();
#endif

// sizeof(unsigned int) = 2 bytes so 65535 is the maximum for delayMicroseconds - switching to delay otherwise
#if REFRESH_DELAY_US > 0 && REFRESH_DELAY_US < 65535
    delayMicroseconds(REFRESH_DELAY_US);
#elif REFRESH_DELAY_US > 0
    delay(REFRESH_DELAY_US/1000);
#endif
}

// Callback function
void serialLoggerButtonCallback(ButtonEvent* e) {
    Serial.print("Button ");
    Serial.print(buttonsName[e->getButton()]);
    Serial.print(" has been ");
    Serial.println(e->isPressed() ? "pressed" : "released");
    Serial.flush();
}

// Callback function
void sdcardLoggerButtonCallback(ButtonEvent* e) {
    writer->writeEvent(e);
}

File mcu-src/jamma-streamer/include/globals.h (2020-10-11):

#ifndef __GLOBALS_HEADER__
#define __GLOBALS_HEADER__

#include <Arduino.h>

#define APP_NAME "NMA Jamma Streamer"
#ifndef APP_VERSION
#define APP_VERSION "master"
#endif

// Special attention to pin numbers because Arduino library pinout macros can be
// confusing...
// As far as I know, PDx are ok whereas PBx are not really what I thought...

// Shift registers
#define PLOAD PD4   // PD4 = Arduino pin 4
#define ENABLE PD5  // PD5 = Arduino pin 5
#define DATA PD6    // PD6 = Arduino pin 6
#define CLOCK PD7   // PD7 = Arduino pin 7

// SD card
#define SD_CS 10    // PB2 = Arduino pin 10 (SS)
#define SD_MOSI 11  // PB3 = Arduino pin 11 (MOSI)
#define SD_MISO 12  // PB4 = Arduino pin 12 (MISO)
#define SD_CLK 13   // PB5 = Arduino pin 13 (SCK)

// Delay in main loop if need be
#ifndef REFRESH_DELAY_US
#define REFRESH_DELAY_US 100000
#endif

// Serial communication speed
#ifndef SERIAL_SPEED
#define SERIAL SPEED 19600
#endif

// Control register to generate a square wave (1KHz) on RTC's SQW pin to count milliseconds via interrupt.
// See page 13 - https://www.mouser.com/datasheet/2/256/DS3231-1513891.pdf
// RS2 RS1 = 1 0 for ~1kHz square wave
#define RTC_CONTROL_REG 0b10001000

// RTC / ATmega interrupt pins configuration
#define SWQ_PIN PCINT11
#define INT_PIN_GRP PINC

#endif  // __GLOBALS_HEADER__

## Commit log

2018-12-11 In progress prototype design
    [jamma-streamer.brd, jamma-streamer.sch]
2018-12-11 Added Micro SDCARD circuitry
    [jamma-streamer.brd, jamma-streamer.sch]
2018-12-11 Added Atmega 328p library
    [jamma-streamer.sch]
2018-12-12 Added atmega328p and begining wiring
    [jamma-streamer.brd, jamma-streamer.sch]
2018-12-15 Schematic with atmega328p wired
    [jamma-streamer.brd, jamma-streamer.sch]
2018-12-16 Adding button detection shift registers
    [jamma-streamer.brd, jamma-streamer.sch]
2018-12-17 Added FTDI USB to serial RS232
    [jamma-streamer.brd, jamma-streamer.sch]
2018-12-18 Alternative routing and thiner vias and routes
    [jamma-streamer.brd, jamma-streamer.sch]
2018-12-20 final board v0.0.1
    [jamma-streamer.brd, jamma-streamer.sch]
2018-12-24 Better routes (unfinished) and audio circuit
    [jamma-streamer.brd, jamma-streamer.sch]
2018-12-26 Rerouting + audio
    [jamma-streamer.brd, jamma-streamer.sch]
2018-12-29 Matching outline with 3.5" jack milling layer
    [jamma-streamer.brd]
2019-01-27 New version including RTC and better alim
    [jamma-streamer.brd, jamma-streamer.sch]
2020-06-17 Updating readme with more info
    [jamma-streamer.brd, jamma-streamer.sch]
2020-06-17 New README, new schematic after burn fixing
    [jamma-streamer.brd, jamma-streamer.sch]
2020-06-18 Added buttons detection atmega code
    [jamma-streamer.brd, jamma-streamer.sch]
2020-06-19 Added Arduino pinout diagram
    [jamma-streamer.brd, jamma-streamer.sch]
2020-06-19 Better routing, elec fixes, doc and sdcard ok
    [jamma-streamer.brd, jamma-streamer.sch]
2020-06-19 Added a callback func for detecting buttons change
2020-06-20 Refacto some parts on the PCB
    - new SDCARD slot (push-push): https://www.mouser.fr/ProductDetail/798-DM3AT-SF-PEJM5
    - new microUSB connector (type B): https://www.mouser.fr/ProductDetail/806-KMMXBSMT35SB30TR
    - resistors replacement for audio (3W) -> need to replace with other
    values
    - resistors replacement for RGB (SMT)
    [jamma-streamer.brd, jamma-streamer.sch]
2020-06-20 Better resistors for video and audio
    [jamma-streamer.brd, jamma-streamer.sch]
2020-06-20 Reorg eagle libraries
    [jamma-streamer.brd, jamma-streamer.sch]
2020-06-20 Changing battery holder to use CR2032
    [jamma-streamer.brd, jamma-streamer.sch]
2020-06-21 Added RTC with milliseconds accuracy
    [jamma-streamer.brd, jamma-streamer.sch]
2020-06-23 Finalization + add jamma connector horiz
    [jamma-streamer.brd, jamma-streamer.sch]
2020-06-23 DRC Sparkfun ok
    [jamma-streamer.brd, jamma-streamer.sch]
2020-06-23 Version sent to PCBWAY
    [jamma-streamer.brd, jamma-streamer.sch]
2020-06-28 Minor changes in schematics (refab not needed)
    [jamma-streamer.brd, jamma-streamer.sch]
2020-06-28 Added info to README for BOM
2020-10-10 Setting correct pins for RTC interrupts and ms counting
    [globals.h, jammaTime.cpp, main.cpp]
2020-10-13 Added generated bom

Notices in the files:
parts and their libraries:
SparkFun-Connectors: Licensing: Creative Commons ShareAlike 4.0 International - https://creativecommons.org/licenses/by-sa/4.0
